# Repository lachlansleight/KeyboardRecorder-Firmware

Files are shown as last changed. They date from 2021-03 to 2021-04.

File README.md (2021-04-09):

# MIDI Recorder Firmware + CAD

My MIDI recorder is a small device that lives plugged into a MIDI instrument (specifically a digital piano) and automatically records and uploads everything played on it for later reference. The core idea is that no input is required, and no feedback is given that recording has started/stopped, so you get 'recording-by-default'. A webserver automatically processes recordings and makes them available for playback via a frontend website.

---

This is the firmware and CAD files for a device that I'm building that automatically records everything I play on my piano. The repository for the server and frontend website can be found [here](https://github.com/lachlansleight/MidiRecorder-Server)

The device is pretty simple - it's an ESP32, some power regulation and MIDI IN / MIDI THRU. Check back soon, I'm actively working on this project right now so CAD files for the enclosure should be coming soon!

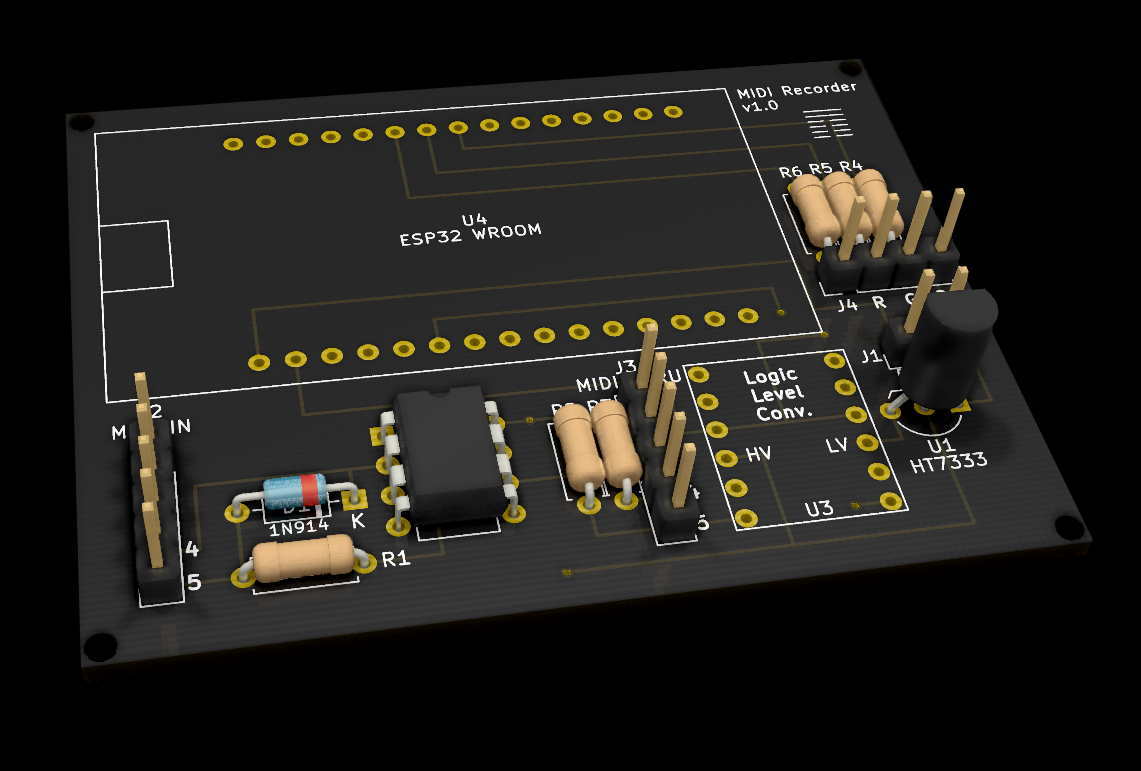
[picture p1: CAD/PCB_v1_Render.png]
MidiRecorder Circuitboard Render


### Bill of Materials

  * ESP32 WROOM (or similar) - note the pinout if you're using my PCB design
  * 6N138 Optocoupler (DIP8)
  * HT7333 Linear Voltage Regulator
  * 1N914 Signal Diode
  * 6 x 220Ω Resistors
  * 4-pin 8mm RGB LED
  * Bidirectional Logic Level Converter (e.g. [this one from sparkfun](https://www.sparkfun.com/products/12009))
  * 2 x 5-pin DIN Jack (panel mount)
  * 1 x DC Barrel Jack (panel mount)
  * 5V 2A DC Power Supply (make sure the barrel size matches your jack size)

### Firmware Setup

  1. Open up the firmware in the Arduino IDE and install [this custom library](https://github.com/FortySevenEffects/arduino_midi_library) (you should be able to find it in the Library Manager
  2. Replace my SSID and passcode with your WiFi credentials (2.4GHz only)
  3. Replace the server with the URL of your custom server instance (see the [server readme for details](https://github.com/lachlansleight/MidiRecorder-Server))
  4. Make sure that line 1 is uncommented (i.e. that `DEBUG_MODE` is defined)
  5. Flash the firmware and examine the serial output (38400 baud) - note the MAC address and ensure WiFi is connecting successfully (reboot the device if you don't see them)
  7. Update the `NEXT_PUBLIC_DEVICE_MAC_ADDRESS` environment variable on the server and redeploy
  8. Try uploading a recording! If it works, comment-out `DEBUG_MODE` and reflash - you're done!

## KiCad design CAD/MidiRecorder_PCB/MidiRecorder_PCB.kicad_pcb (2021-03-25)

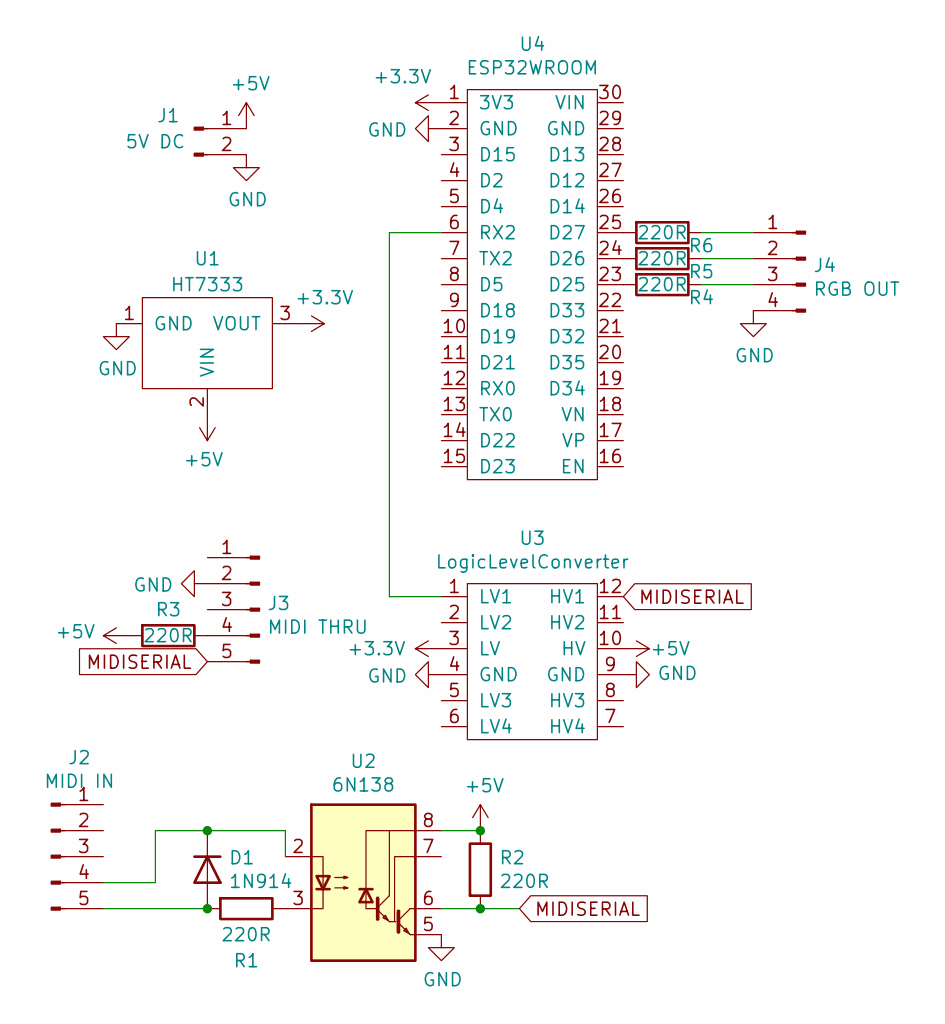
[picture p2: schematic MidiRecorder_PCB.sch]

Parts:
D1: 1N914; D_DO-35_SOD27_P7.62mm_Horizontal
J1: 5V DC; PinHeader_1x02_P2.54mm_Vertical
J2: MIDI IN; PinHeader_1x05_P2.54mm_Vertical
J3: MIDI THRU; PinHeader_1x05_P2.54mm_Vertical
J4: RGB OUT; PinHeader_1x04_P2.54mm_Vertical
R1, R2, R3, R4, R5, R6: 220R; R_Axial_DIN0207_L6.3mm_D2.5mm_P7.62mm_Horizontal
U1: HT7333; TO-92L_Inline_Wide
U2: 6N138; DIP-8_W7.62mm
U3: LogicLevelConverter; LogicLevelShifter
U4: ESP32WROOM

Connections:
+3V3: U1.3 (VOUT), U3.3 (LV), U4.1 (3V3)
+5V: J1.1, R2.1, R3.2, U1.2 (VIN), U2.8 (VCC), U3.10 (HV)
GND: J1.2, J3.2, J4.4, U1.1 (GND), U2.5 (GND), U3.4 (GND), U3.9 (GND), U4.2 (GND)
MIDISERIAL: J3.5, R2.2, U2.6 (VO2), U3.12 (HV1)
unnamed: D1.1 (K), J2.4, U2.2 (C1)
unnamed: D1.2 (A), J2.5, R1.2
unnamed: J3.4, R3.1
unnamed: J4.1, R6.1
unnamed: J4.2, R5.1
unnamed: J4.3, R4.1
unnamed: R1.1, U2.3 (C2)
unnamed: R4.2, U4.23 (D25)
unnamed: R5.2, U4.24 (D26)
unnamed: R6.2, U4.25 (D27)
unnamed: U3.1 (LV1), U4.6 (RX2)

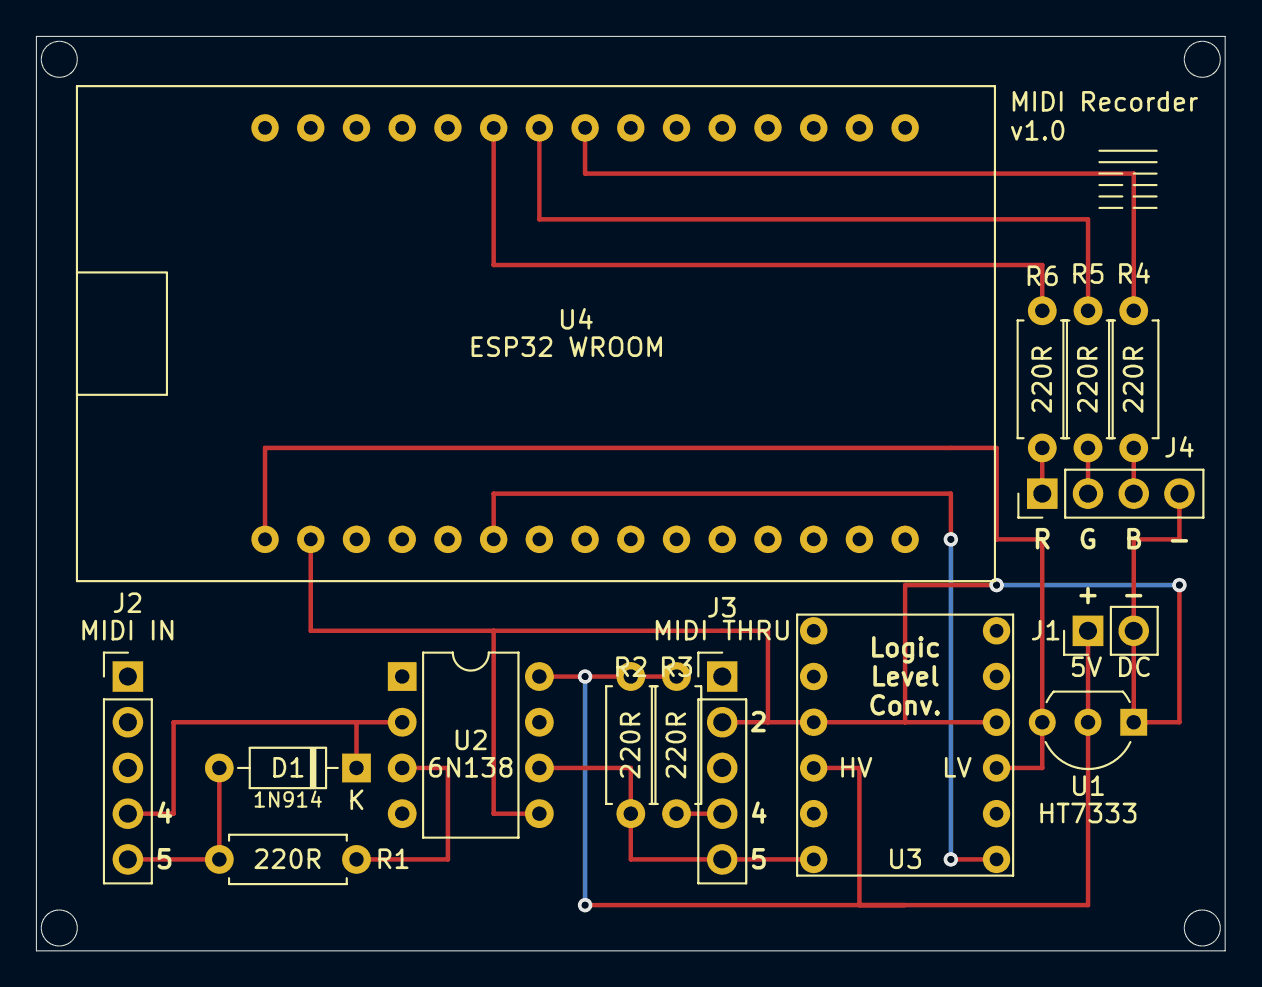
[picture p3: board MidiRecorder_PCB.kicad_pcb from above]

Board: 2 copper layers, 66.0 x 50.8 mm, 15 parts (0 on the bottom side), 15 nets.

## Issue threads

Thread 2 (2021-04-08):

Recordings shorter than 10 seconds shouldn't be added

lachlansleight, 2021-04-08:
I think I'm currently discarding recordings with 10 or fewer messages, but in practise it seems like 10 seconds is a sensible cutoff point for recordings. That reasonably safely discards most of the 'play a chord while walking past' kind of things.

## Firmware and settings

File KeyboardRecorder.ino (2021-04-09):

//#define DEBUG_MODE

struct Message {
    byte onOffPitch;
    byte isPedalVelocity;
    byte timeA;
    byte timeB;
    byte timeFrac;
};


#include <WiFi.h>
#include <HTTPClient.h>
//Replace these with your WiFi credentials (2.4GHz only)
//Also...please don't come to my house and hack my WiFi with these!
const char* ssid     = "WhatFight4";
const char* password = "dumplingsatnoon!";
String server = "https://midirecorder.vercel.app";
String path = "/api/upload";
String mac = WiFi.macAddress();

#include <MIDI.h>
MIDI_CREATE_INSTANCE(HardwareSerial, Serial2, MIDI);

//RUNTIME VARS
unsigned long songStartTime = 0;
unsigned long songTime = 0;
unsigned long lastNoteTime = 0;
bool runningSong = false;

uint8_t* messageBuffer;
unsigned int messageIndex = 0;
unsigned int messageCount = 0;


//CONFIG
#ifdef DEBUG_MODE
    long timeoutTime = 5000; //5 seconds silence = end song (!!for testing!!)
#else
    long timeoutTime = 60000; //60 seconds silence = end song
#endif

#define PIN_LED_R 25
#define PIN_LED_G 24
#define PIN_LED_B 23



void setLedColor(byte r, byte g, byte b) {
    ledcWrite(0, r);
    ledcWrite(1, g);
    ledcWrite(2, b);
}

void errorFlash()
{
    //flash LED white/red, then fade
    
    byte last = 255;
    for(byte i = 255; i >= 0; i--) {
        if(i > last) break;
        last = i;
        
        setLedColor(255, i, i);
        delay(1);
    }
    last = 0;
    for(byte i = 0; i <= 255; i++) {
        if(i < last) break;
        last = i;
        
        setLedColor(255, i, i);
        delay(1);
    }
    last = 255;
    for(byte i = 255; i >= 0; i--) {
        if(i > last) break;
        last = i;
        
        setLedColor(255, i, i);
        delay(1);
    }
    delay(500);
    last = 255;
    for(byte i = 255; i >= 0; i--) {
        if(i > last) break;
        last = i;
        
        setLedColor(i, 0, 0);
        delay(5);
    }

    setLedColor(0, 0, 0);
}

void wifiSuccessFlash()
{
    byte last = 255;
    for(byte i = 255; i >= 0; i--) {
        if(i > last) break;
        last = i;
        
        setLedColor(i, i * 0.5 + 128, 255);
        delay(1);
    }
    last = 255;
    for(byte i = 255; i >= 0; i--) {
        if(i > last) break;
        last = i;
        
        setLedColor(0, i * 0.5, i);
        delay(5);
    }

    setLedColor(0, 0, 0);
}

void setup() {
    //allocate this memory first before anything else can break into my beautiful, pristine chunk
    messageBuffer = (uint8_t*)calloc(100000, sizeof(byte));
    
    //Set up LED output
    ledcSetup(0, 5000, 8);
    ledcSetup(1, 5000, 8);
    ledcSetup(2, 5000, 8);
    
    ledcAttachPin(PIN_LED_R, 0);
    ledcAttachPin(PIN_LED_G, 1);
    ledcAttachPin(PIN_LED_B, 2);

    
    Serial.begin(38400);
    delay(10);

    //connect to WiFi
    #ifdef DEBUG_MODE
    Serial.print("Connecting to ");
    Serial.print(ssid);
    Serial.print(" with MAC address ");
    Serial.println(mac);    
    #endif
    WiFi.begin(ssid, password);

    boolean waitingA = false;
    while (WiFi.status() != WL_CONNECTED) {
        if(waitingA) {
            setLedColor(0, 0, 0);
        } else {
            setLedColor(0, 25, 50);
        }
        waitingA = !waitingA;
        delay(500);
        #ifdef DEBUG_MODE
        Serial.print(".");
        #endif
    }
    wifiSuccessFlash();

    #ifdef DEBUG_MODE
    Serial.println("WiFi connected!");
    Serial.print("IP address: ");
    Serial.println(WiFi.localIP());
    Serial.println("");
    #endif

    //WIFI is now connected, we can start listening for MIDI
    
    MIDI.setHandleNoteOn(handleNoteOn);
    MIDI.setHandleNoteOff(handleNoteOff);
    MIDI.setHandleControlChange(handleControlChange);
    MIDI.begin();
}

void loop() {
    //song auto-ends if there's been a certain amount of time passed with no new messages
    //todo - this should probably suspend if there are notes held. Maybe.
    if(runningSong) {
        songTime = (unsigned long)(millis() - songStartTime);
        if(songTime - lastNoteTime > timeoutTime) {
          endSong();
        }
    }
    MIDI.read();
}

void printByte(byte in) {
    byte i = 7;
    while(i >= 0 && i < 8) {
        Serial.print(bitRead(in, i));
        i--;
    }
}

//creates five message bytes from the basic data
Message createMessage(bool onOff, byte pitch, byte velocity, bool isPedal, long songMillis) {
    //time is stored in three bytes - two for the number of seconds, and one for the number of milliseconds (with 4ms precision)
    float songSeconds = (float)songMillis / 1000.0;
    unsigned int wholeSeconds = (unsigned int)songSeconds;
    unsigned int fracSeconds = (unsigned int)(songMillis % 1000);
    fracSeconds /= 4;

    //first byte contains on/off status, and pitch
    byte firstByte = onOff << 7 | (pitch & 0b01111111);
    //second byte contains whether this message is a pedal movement or not, and velocity
    byte secondByte = isPedal << 7 | (velocity & 0b01111111);
    //time bytes, as mentioned above
    byte thirdByte = wholeSeconds >> 8;
    byte fourthByte = wholeSeconds & 0b0000000011111111;
    byte fifthByte = (byte)fracSeconds;

    Message newMessage{
        firstByte,
        secondByte,
        thirdByte,
        fourthByte,
        fifthByte
    };
    #ifdef DEBUG_MODE
    printMessage(newMessage);
    Serial.println("\t" + String(onOff) + "\t" + String(pitch) + "\t" + String(velocity) + "\t    " + String(isPedal) + "\t" + String(songMillis));
    Serial.println("");
    #endif
    return newMessage;
}

//creates a message from the basic data and adds the five resulting bytes to the buffer
//also starts a new song if necessary, and updates the last played note time for calculating timeout
void addMessage(bool onOff, byte pitch, byte velocity, bool isPedal) {
    if(!runningSong) startSong();

    unsigned long songTime = (unsigned long)(millis() - songStartTime);
    
    Message newMessage = createMessage(onOff, pitch, velocity, isPedal, songTime);
    messageBuffer[messageIndex] = newMessage.onOffPitch;
    messageIndex++;
    messageBuffer[messageIndex] = newMessage.isPedalVelocity;
    messageIndex++;
    messageBuffer[messageIndex] = newMessage.timeA;
    messageIndex++;
    messageBuffer[messageIndex] = newMessage.timeB;
    messageIndex++;
    messageBuffer[messageIndex] = newMessage.timeFrac;
    messageIndex++;
    
    messageCount++;
    lastNoteTime = songTime;
}

void printMessage(Message message) {
    Serial.print("  ");
    printByte(message.onOffPitch);
    Serial.print("  ");
    printByte(message.isPedalVelocity);
    Serial.print("  ");
    printByte(message.timeA);
    Serial.print("  ");
    printByte(message.timeB);
    Serial.print("  ");
    printByte(message.timeFrac);
    Serial.println("");
}

//uploads the current song buffer to the server to be further processed
void uploadSong()
{
    if(WiFi.status()== WL_CONNECTED){
        HTTPClient http;

        #ifdef DEBUG_MODE
        Serial.println("Making request to " + (server + path));
        #endif
        http.begin((server + path).c_str());
        
        //data
        http.addHeader("Content-Type", "application/octet-stream");
        http.addHeader("Authorization", "Basic " + mac);
        int httpResponseCode = http.POST(messageBuffer, messageCount * 5);
        
        if (httpResponseCode>0) {
            if(httpResponseCode >= 200 && httpResponseCode <= 299) {
                #ifdef DEBUG_MODE
                String payload = http.getString();
                Serial.print("HTTP Response: ");
                Serial.print(httpResponseCode);
                Serial.print(" - ");
                Serial.println(payload);
    
                wifiSuccessFlash();
                #endif
            } else {
                if(httpResponseCode >= 500) {
                    #ifdef DEBUG_MODE
                    Serial.println("Error - server error " + String(httpResponseCode));
                    #endif
                    errorFlash();
                } else {
                    #ifdef DEBUG_MODE
                    Serial.println("Error - request error " + String(httpResponseCode));
                    #endif
                    errorFlash();
                }
            }
        }
        else {
            #ifdef DEBUG_MODE
            if(httpResponseCode == -1) Serial.println("Error - Connection_Refused (Code -1)");
            else if(httpResponseCode == -2) Serial.println("Error - Send Header Failed (Code -2)");
            else if(httpResponseCode == -3) Serial.println("Error - Send Payload Failed (Code -3)");
            else if(httpResponseCode == -4) Serial.println("Error - Not Connected (Code -4)");
            else if(httpResponseCode == -5) Serial.println("Error - Connection Lost (Code -5)");
            else if(httpResponseCode == -6) Serial.println("Error - No Stream (Code -6)");
            else if(httpResponseCode == -7) Serial.println("Error - No Http Server (Code -7)");
            else if(httpResponseCode == -8) Serial.println("Error - Not Enough RAM (Code -8)");
            else if(httpResponseCode == -9) Serial.println("Error - Encoding (Code -9)");
            else if(httpResponseCode == -10) Serial.println("Error - Stream Write (Code -10)");
            else if(httpResponseCode == -11) Serial.println("Error - Read Timeout (Code -11)");
            else Serial.println("Error - Unexpected error code " + String(httpResponseCode));
            #endif

            //flash LED white/red, then fade
            errorFlash();
        }
        // Free resources
        http.end();
    } else {
        #ifdef DEBUG_MODE
        Serial.println("WiFi Disconnected");
        #endif
        errorFlash();
    }
}

void startSong()
{
    #ifdef DEBUG_MODE
    Serial.println("====================STARTING SONG===================");
    #endif
    songStartTime = millis();
    runningSong = true;
}

//resets everything for a new song, and uploads the song if there have been messages entered
void endSong()
{
    if(messageCount > 10) {
        uploadSong();
    }

    #ifdef DEBUG_MODE
    Serial.println("====================ENDING SONG===================");
    #endif
    messageIndex = 0;
    messageCount = 0;
    runningSong = false;
}





void handleNoteOn(byte channel, byte pitch, byte velocity)
{
    //Serial.println("ON\t" + String(channel) + "\t" + String(pitch) + "\t" + String(velocity));
    addMessage(true, pitch, velocity, false);
}

void handleNoteOff(byte channel, byte pitch, byte velocity)
{
    //Serial.println("OFF\t" + String(channel) + "\t" + String(pitch) + "\t" + String(velocity));
    addMessage(false, pitch, velocity, false);
}

void handleControlChange(byte channel, byte number, byte value)
{
    //Serial.println("CC\t" + String(channel) + "\t" + String(number) + "\t" + String(value));
    if(number == 64) {
        //dampen pedal
        if(value == 127) addMessage(true, 0, 0, true);
        else addMessage(true, 0, 0, false);
    } else if(number == 67) {
        //sost pedal - could use for some kind of input?
        //I'm thinking a hold of three seconds on sost should discard the current song without uploading
    } else {
        //unknown / uncared-about
    }
}

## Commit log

2021-03-23 feat: Basic ESP32 MIDI Input working
    + Holy fucking god that was annoying
2021-03-23 fix: Make recordings not upload if they have less than 10 messages
    [KeyboardRecorder.ino]
2021-03-24 feat: Add RGB LED and maybe improve message count problem with calloc
    [KeyboardRecorder.ino]
2021-03-25 feat: Add initial version of PCB (untested)
    [MidiRecorder_PCB.kicad_pcb, MidiRecorder_PCB.sch]
2021-03-25 fix: Minor PCB updates
    [MidiRecorder_PCB.kicad_pcb]
2021-03-25 fix: Update LED pins to match PCB
    [KeyboardRecorder.ino]
2021-03-25 fix: Disconnect 5V from 3V3 oops
    [MidiRecorder_PCB.kicad_pcb]
2021-04-09 feat: Add 400 and 500 error reporting
    [KeyboardRecorder.ino]
